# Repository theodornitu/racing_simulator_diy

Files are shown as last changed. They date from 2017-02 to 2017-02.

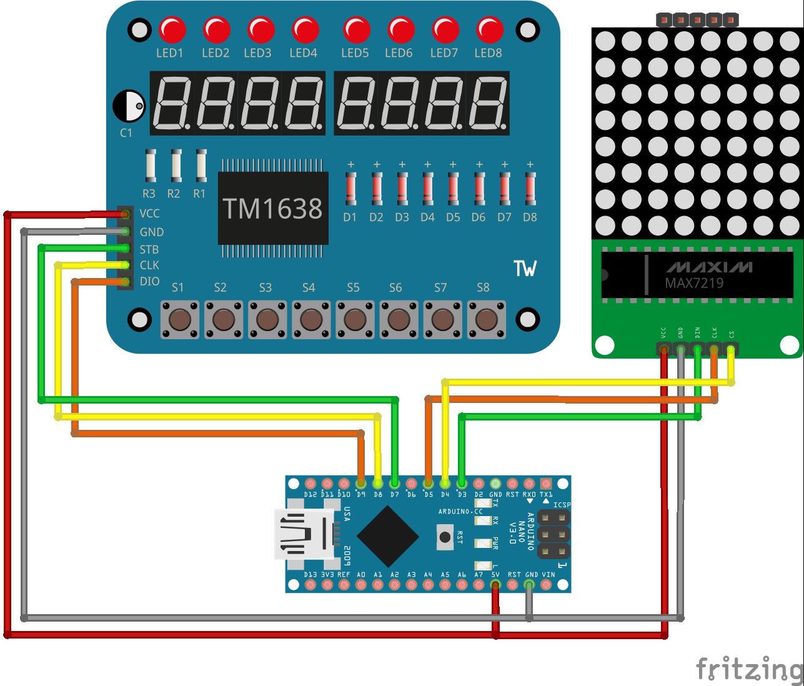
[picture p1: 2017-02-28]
Fritzing Sketch_bb.jpg

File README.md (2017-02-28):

# racing_simulator_diy
Some files that would help building a DIY racing simulator.

https://www.youtube.com/watch?v=rtt3L1Z49OM

Pentru pasionatii de simulatoare auto, pentru amatorii de gadget-uri tech, am pus cap la cap un
device pe care il puteti confectiona acasa, cu piese relativ ieftine si cu un rezultat foarte incurajator.

Toate piesele se pot cumpara de pe magazinul nostru, www.unda.tech/magazin . Folia de
carbon este optionala si nu este inclusa in KIT-ul disponibil online, aceasta se poate fabrica cu usurinta
urmand pasii din tutorial.

The software was provided by SimHub and is 100% their property.
For more information visit: https://github.com/zegreatclan/AssettoCorsaTools/wiki

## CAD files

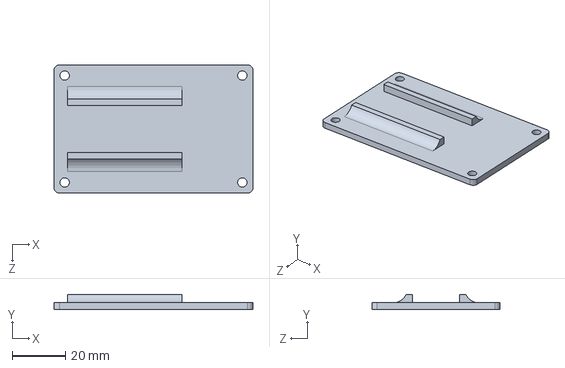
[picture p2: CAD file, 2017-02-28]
Parts/TM1368 backplate ard nano.SLDPRT
74.5 x 5.50 x 48.0 mm

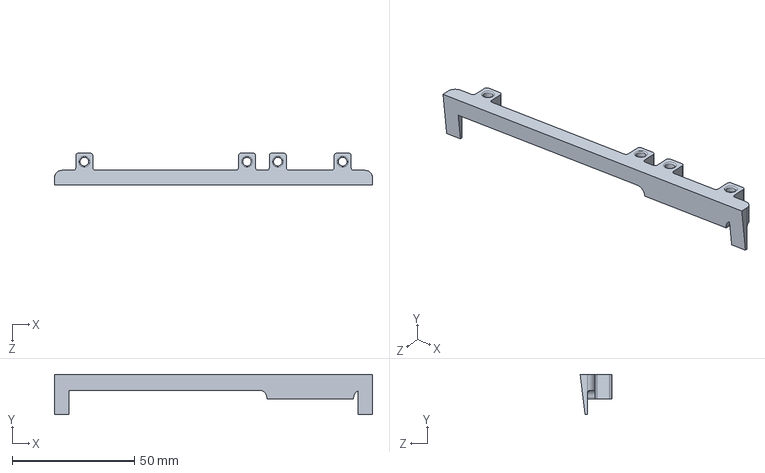
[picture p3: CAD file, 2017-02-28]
Parts/TM1368 Front_plate_and_feet.SLDPRT
130.0 x 16.4 x 13.0 mm

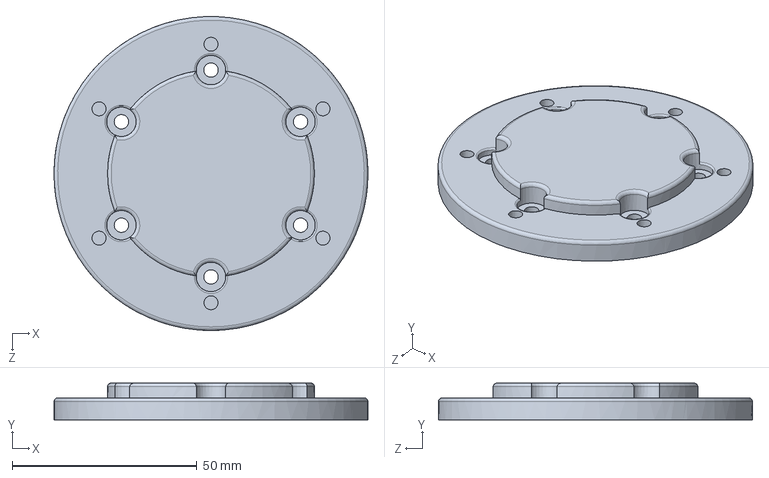
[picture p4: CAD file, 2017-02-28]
Parts/G29 Adapter.SLDPRT
85.0 x 10.0 x 85.0 mm

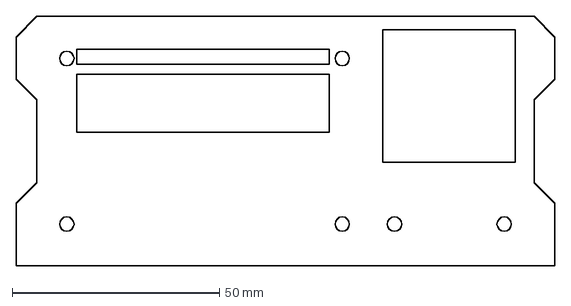
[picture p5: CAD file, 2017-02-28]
Parts/LCD_Dash_Carbon_Cut.DXF
130.0 x 60.1 mm

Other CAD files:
Parts/Part1.SLDPRT
Parts/G29 Adapter.STL
Parts/TM1368 Front_plate_and_feet.STL
Parts/TM1368 backplate ard nano.STL

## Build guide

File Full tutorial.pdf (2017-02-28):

## RACING DASH SIMULATOR

_____________________________________________________________________________________

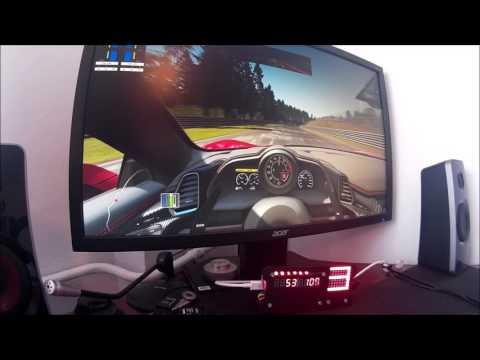
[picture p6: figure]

Pentru pasionatii de simulatoare auto, pentru amatorii de gadget-uri tech, am pus cap la cap un device pe care il puteti confectiona acasa, cu piese relativ ieftine si cu un rezultat foarte incurajator.

Lista componente si materiale necesare:

NUME | CANTITATE | MAGAZIN | PRET
TM1638 Keypad | 1 | UNDA Tech (https://magazin.unda.tech/ro/extensii/689-tm1638-keypad-module.html) | 44.9
Arduino Nano128P | 1 | UNDA Tech (https://magazin.unda.tech/ro/arduino/422-placa-de-dezvoltare-nano-168p.html?search_query=nano&results=4) | 19,9 RON
MAX7219 Dot Matrix | 1 | UNDA Tech (https://magazin.unda.tech/ro/tehnologie-led/212-max7219-diy.html?search_query=max&results=63) | 20 RON
Cabluri / fire diverse | 1 | UNDA Tech (https://magazin.unda.tech/ro/search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) | 10 RON
Panou plexiglass | 1 | UNDA Tech (https://magazin.unda.tech/ro/home/688-kit-panou-simulator-racing.html) | 34,9 RON
Set imprimat 3D
Folie carbon panou | OPTIONAL
TOTAL: 129,8 RON

Toate piesele se pot cumpara de pe magazinul nostru, www.unda.tech/magazin . Folia de carbon este optionala si nu este inclusa in KIT-ul disponibil online, aceasta se poate fabrica cu usurinta urmand pasii din tutorial.

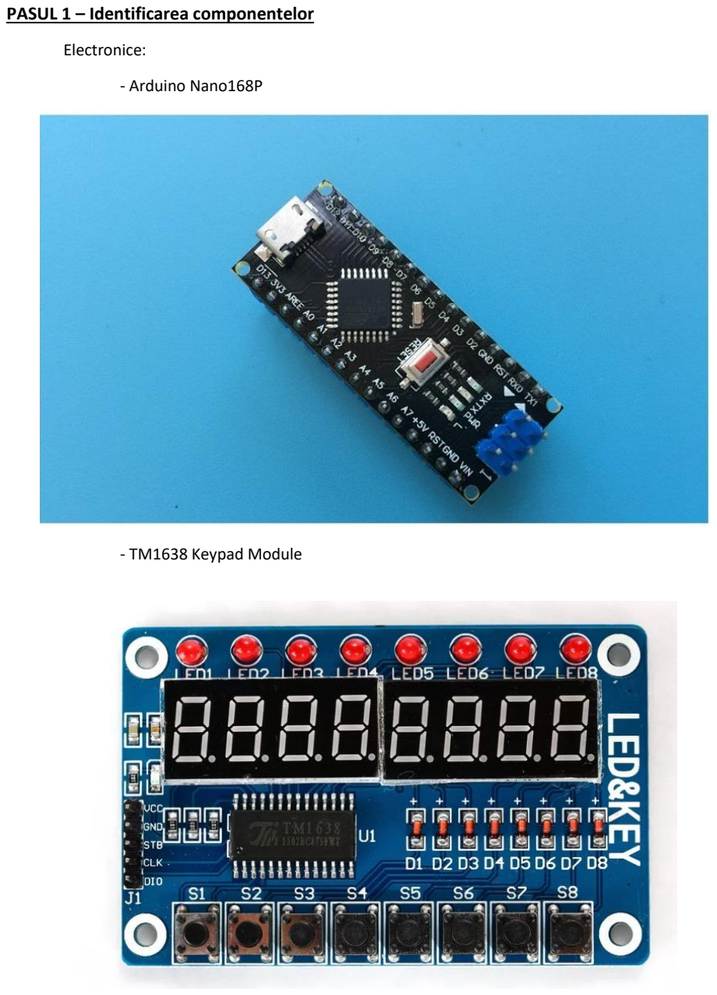
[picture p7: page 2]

PASUL 1 – Identificarea componentelor

Electronice:

- Arduino Nano168P
- TM1638 Keypad Module

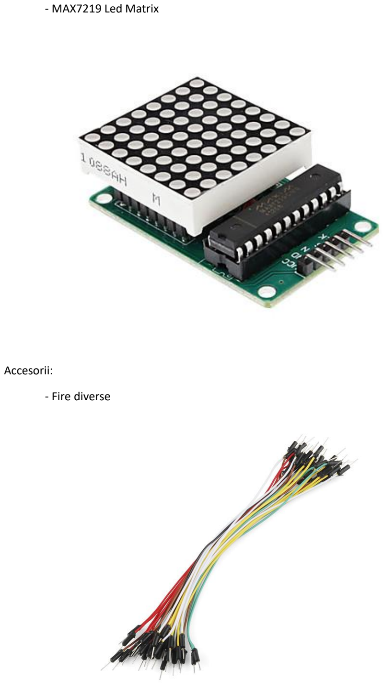
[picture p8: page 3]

- MAX7219 Led Matrix

Accesorii:

- Fire diverse

- Kit Panou plexiglass + piese imprimate 3D

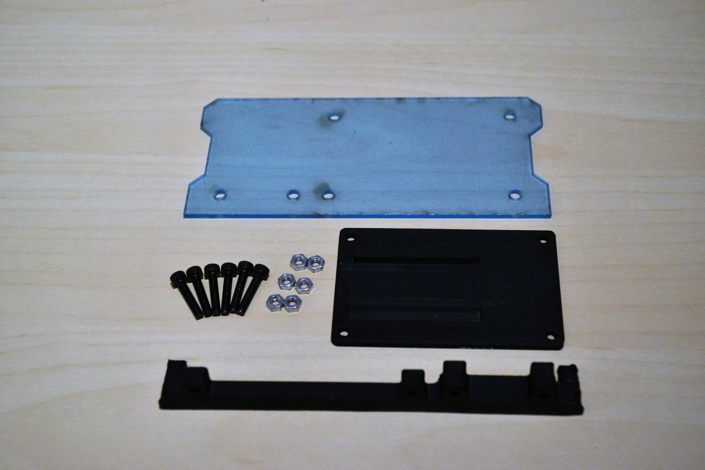
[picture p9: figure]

* kit-ul contine: - panou plexiglass transparent

- suport arduino nano ( backplate )
- stand Keypad si Led Matrix
- M3x25 (6buc) si M3 Nuts (6buc)

PASUL 2 – Conectarea componentelor electronice

Conectarea componentelor se va face dupa urmatoarea schema :

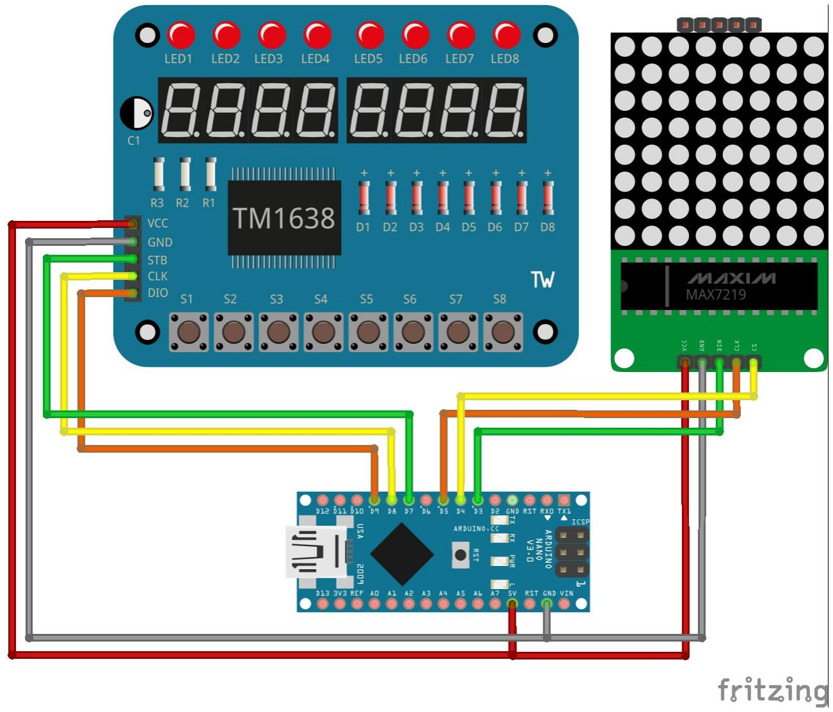
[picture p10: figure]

Part | Part Pin | Arduino Nano Pin
TM1638 KEYPAD MODULE | VCC | 5V
| GND | GND
| STB | D7
| CLK | D8
| DIO | D9
MAX7219 LED MATRIX MODULE | VCC | 5V
| GND | GND
| DIN | D3
| CLK | D5
| CS | D4

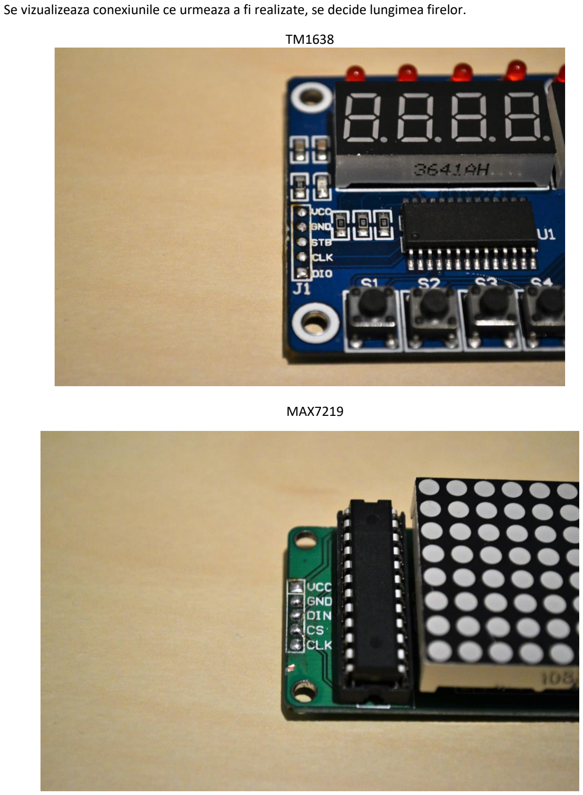
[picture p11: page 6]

Se vizualizeaza conexiunile ce urmeaza a fi realizate, se decide lungimea firelor.

TM1638

MAX7219

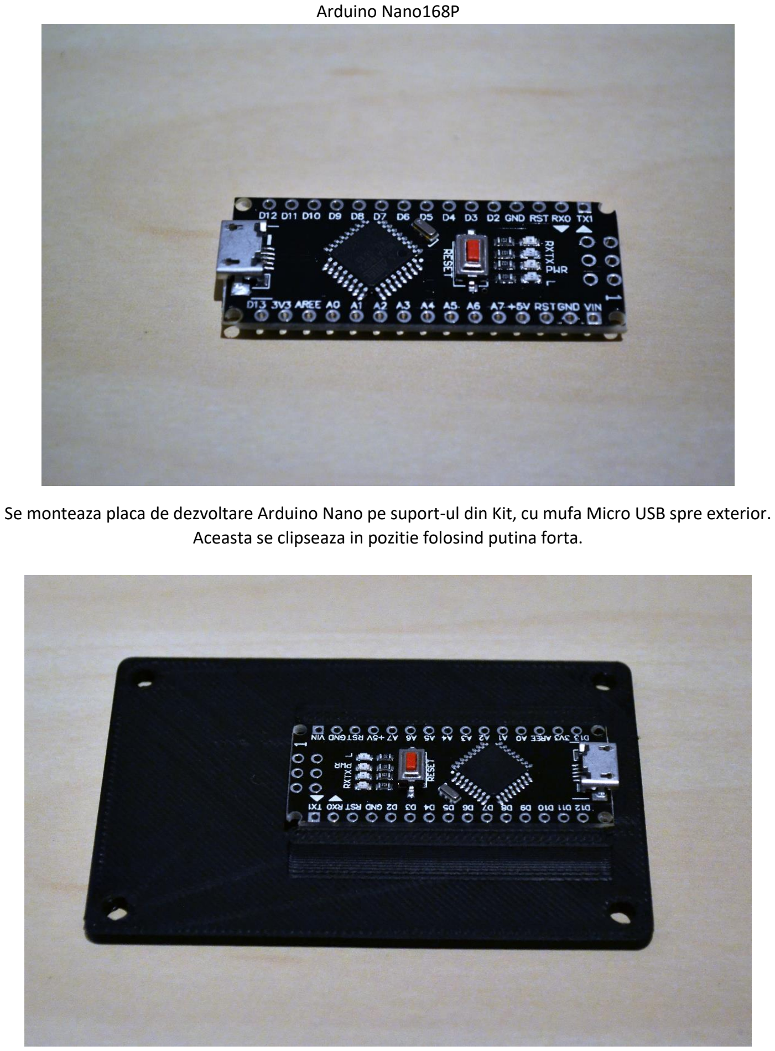
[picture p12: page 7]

Arduino Nano168P

Se monteaza placa de dezvoltare Arduino Nano pe suport-ul din Kit, cu mufa Micro USB spre exterior. Aceasta se clipseaza in pozitie folosind putina forta.

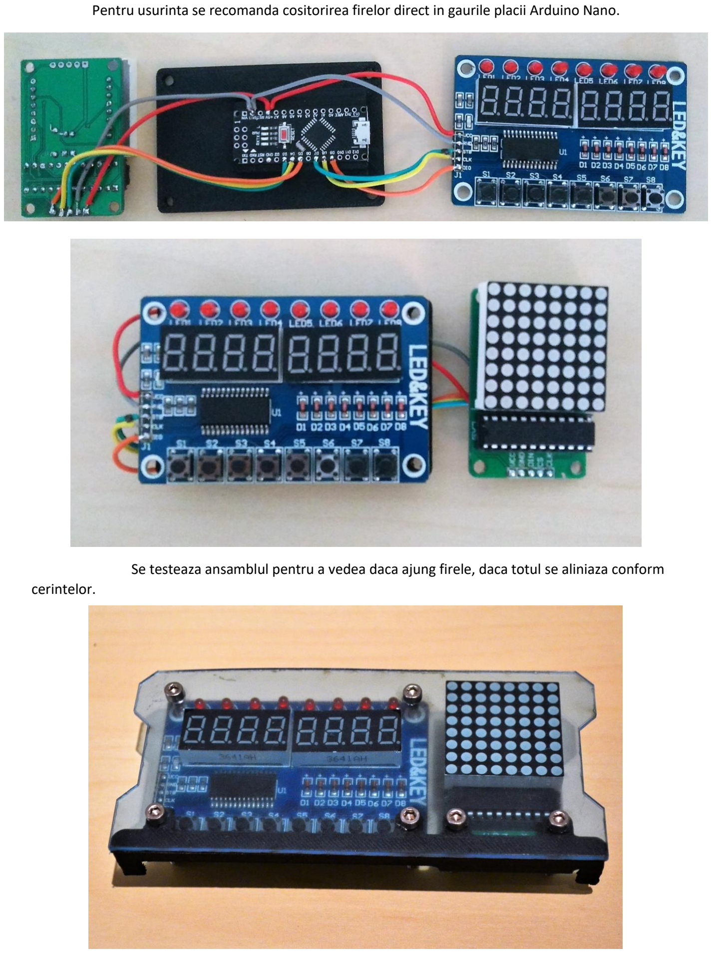
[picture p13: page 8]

Pentru usurinta se recomanda cositorirea firelor direct in gaurile placii Arduino Nano.

Se testeaza ansamblul pentru a vedea daca ajung firele, daca totul se aliniaza conform cerintelor.

PASUL 3 – Folie Carbon ( OPTIONAL )

- Se imprima desenul PDF atasat, folosind scara 1:1 .

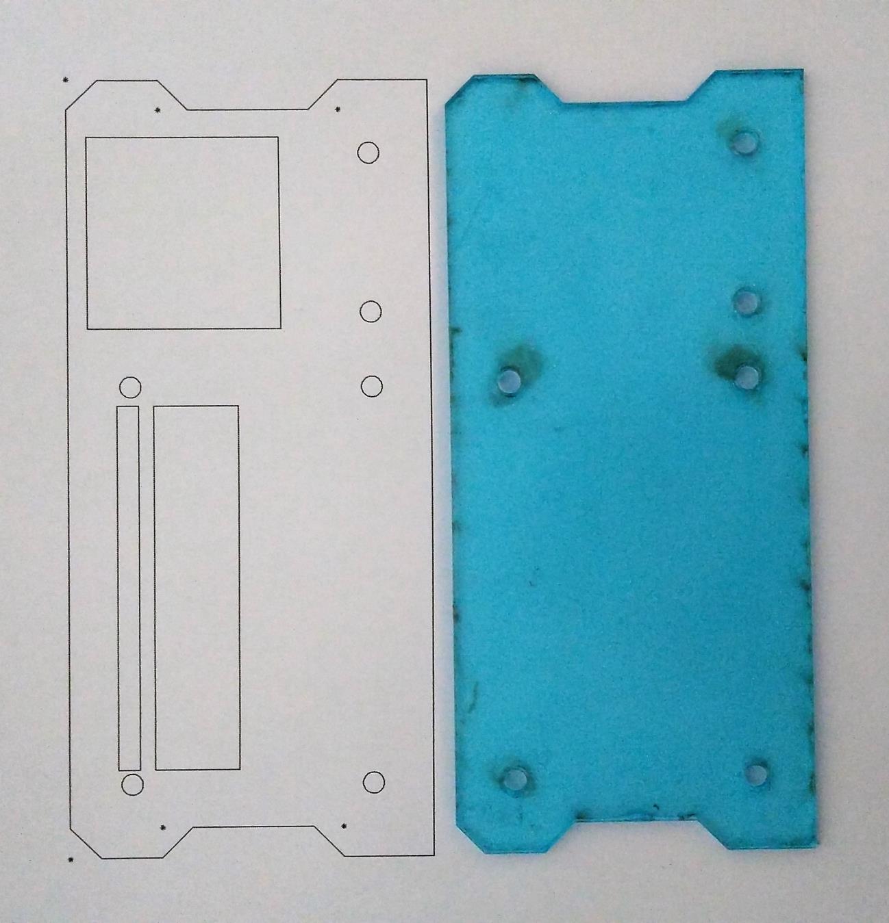
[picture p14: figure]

- folosind o rigla metalica si o lama de precizie ( sau un cutit foarte bine ascutit ) , se taie conturul imprimat si se decupeaza dreptunghiurile din interior. Daca aveti acces la un cutter plotter, desenele in format DXF vor fi disponibile in sectiunea resurse.

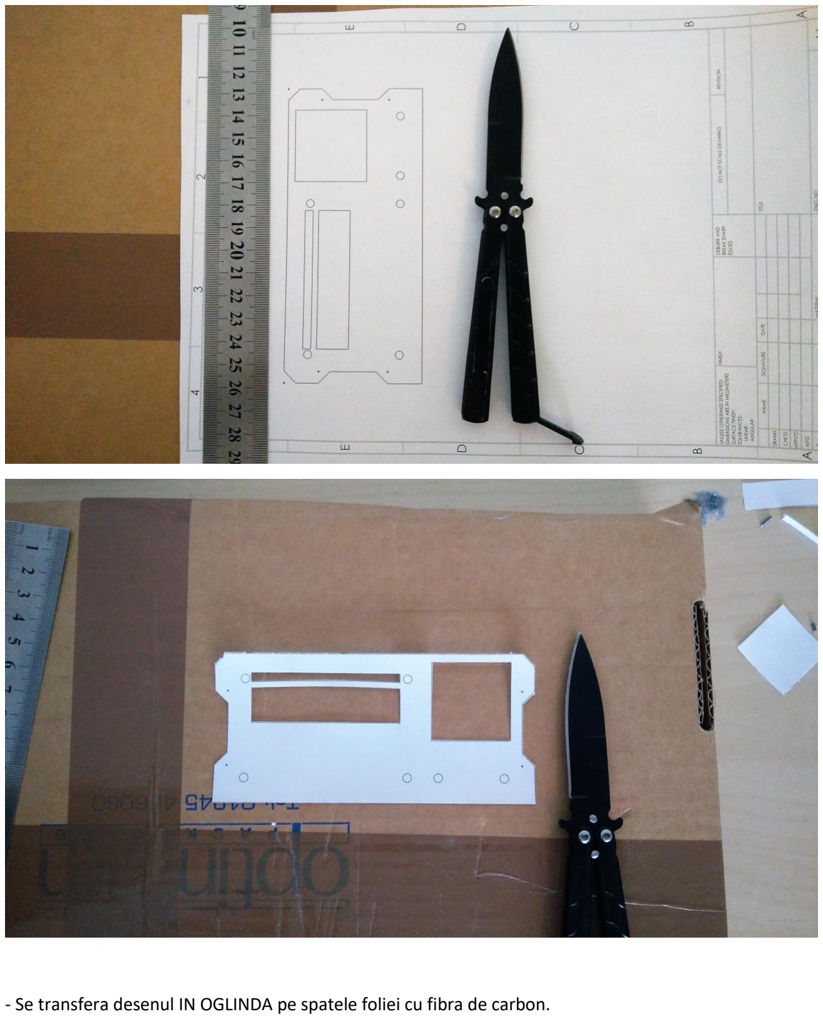
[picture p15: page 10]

- Se transfera desenul IN OGLINDA pe spatele foliei cu fibra de carbon.

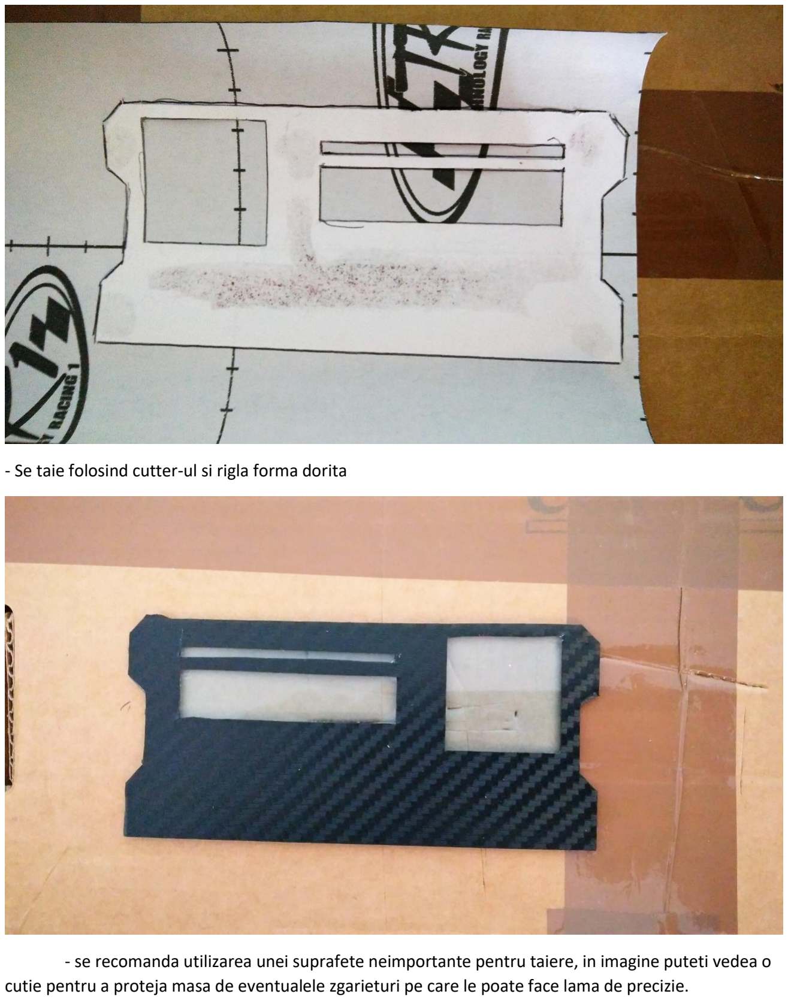
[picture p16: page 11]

- Se taie folosind cutter-ul si rigla forma dorita
- se recomanda utilizarea unei suprafete neimportante pentru taiere, in imagine puteti vedea o cutie pentru a proteja masa de eventualele zgarieturi pe care le poate face lama de precizie.

- se lipeste folia pe panoul de plexiglass si se curata eventualele imperfectiuni ramase in urma taierii:
- Se inteapa gaurile pentru suruburi si se introduc suruburile in gaurile lor. Se adauga stand-ul imprimat 3D peste acestea:

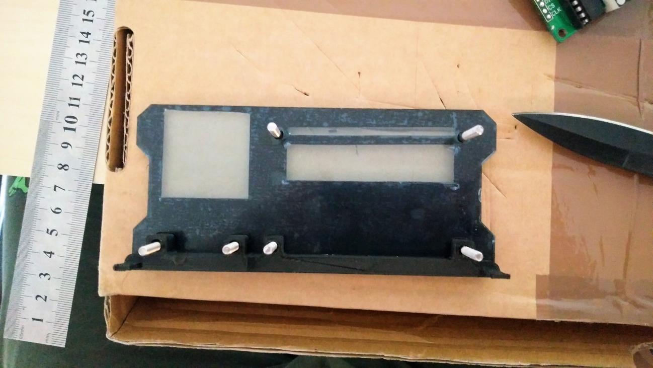
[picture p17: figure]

- Se monteaza modulul Keypad, Matrix si Arduino Nano pe panou utilizand suruburile si piulitele necesare (6 buc M3x25 si 6 buc piulite ). Se adauga folie carbon in zonele cu pini expusi pentru a preveni eventualele scurt-uri nedorite.

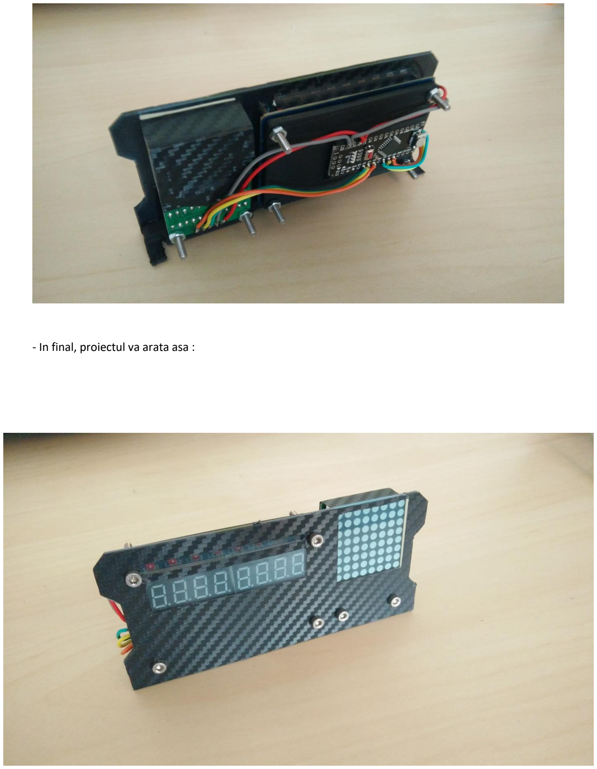
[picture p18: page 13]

- In final, proiectul va arata asa :

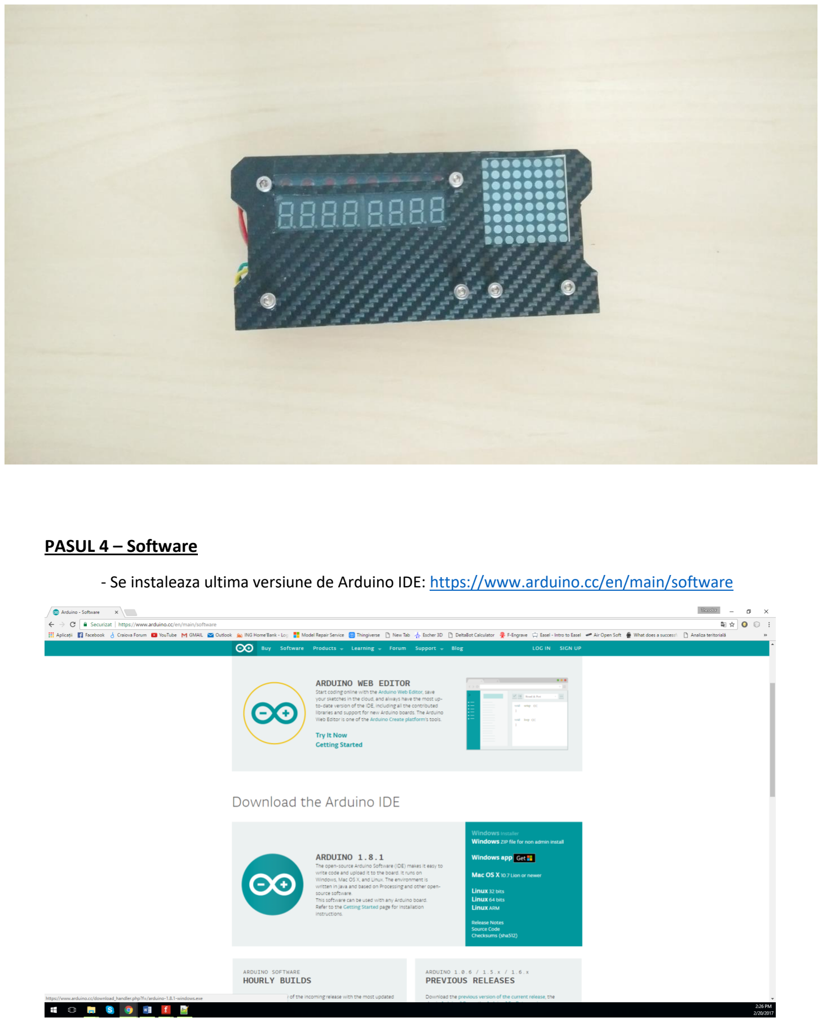
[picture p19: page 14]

PASUL 4 – Software

- Se instaleaza ultima versiune de Arduino IDE: https://www.arduino.cc/en/main/software

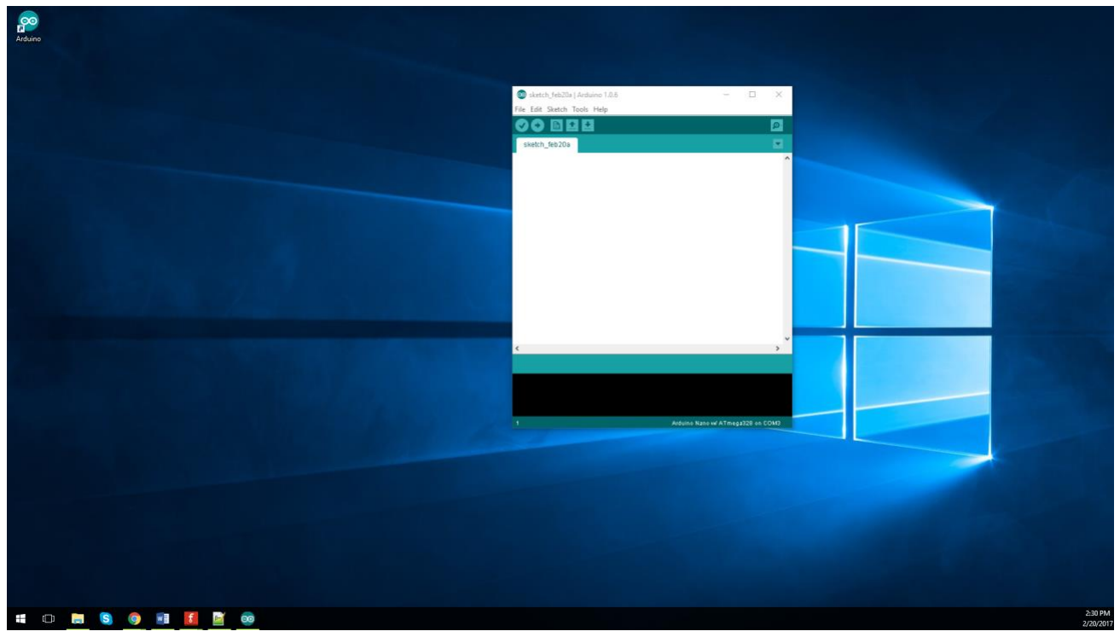
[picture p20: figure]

- Se instaleaza librariile necesare din locatia : Racing Simulator DIY Dash > Libraries . Acestea se copiaza in <<Arduino Install Folder>> > Libraries
- Se deschide codul sursa din locatia : Racing Simulator DIY Dash > Code > DisplayClientV2 > DisplayClientV2.ino
- Se selecteaza Arduino Nano168P (sau, in cazul folosirii unui arduino Nano328P, se selecteaza acesta) , port-ul la care se poate vedea placa de dezvoltare si se apasa butonul Upload

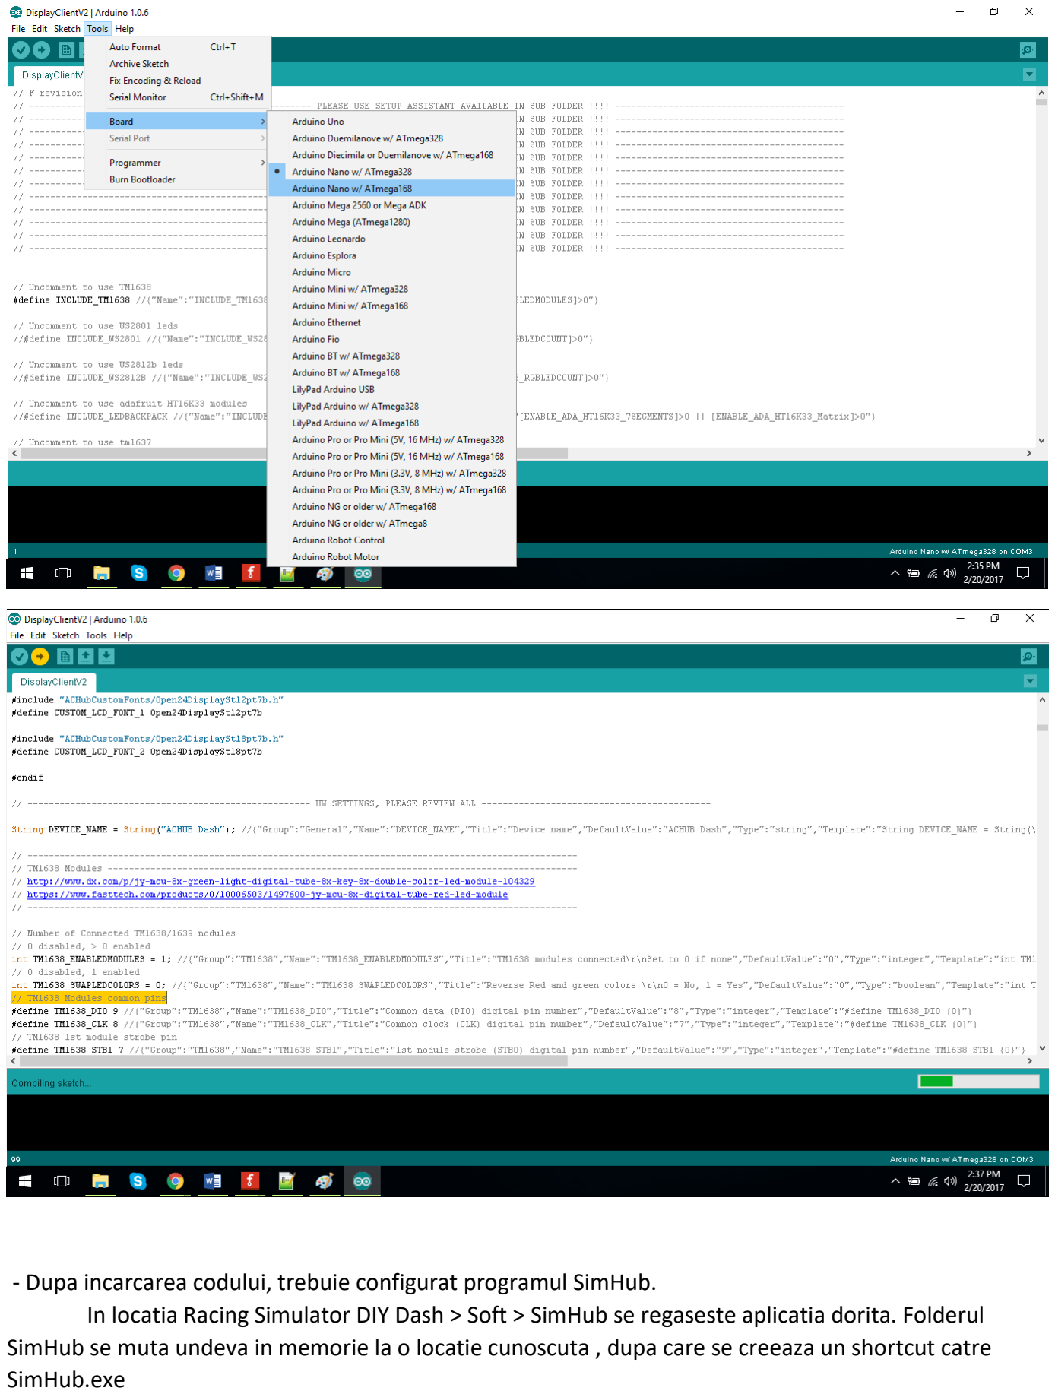
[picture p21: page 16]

- Dupa incarcarea codului, trebuie configurat programul SimHub.
In locatia Racing Simulator DIY Dash > Soft > SimHub se regaseste aplicatia dorita. Folderul SimHub se muta undeva in memorie la o locatie cunoscuta , dupa care se creeaza un shortcut catre SimHub.exe

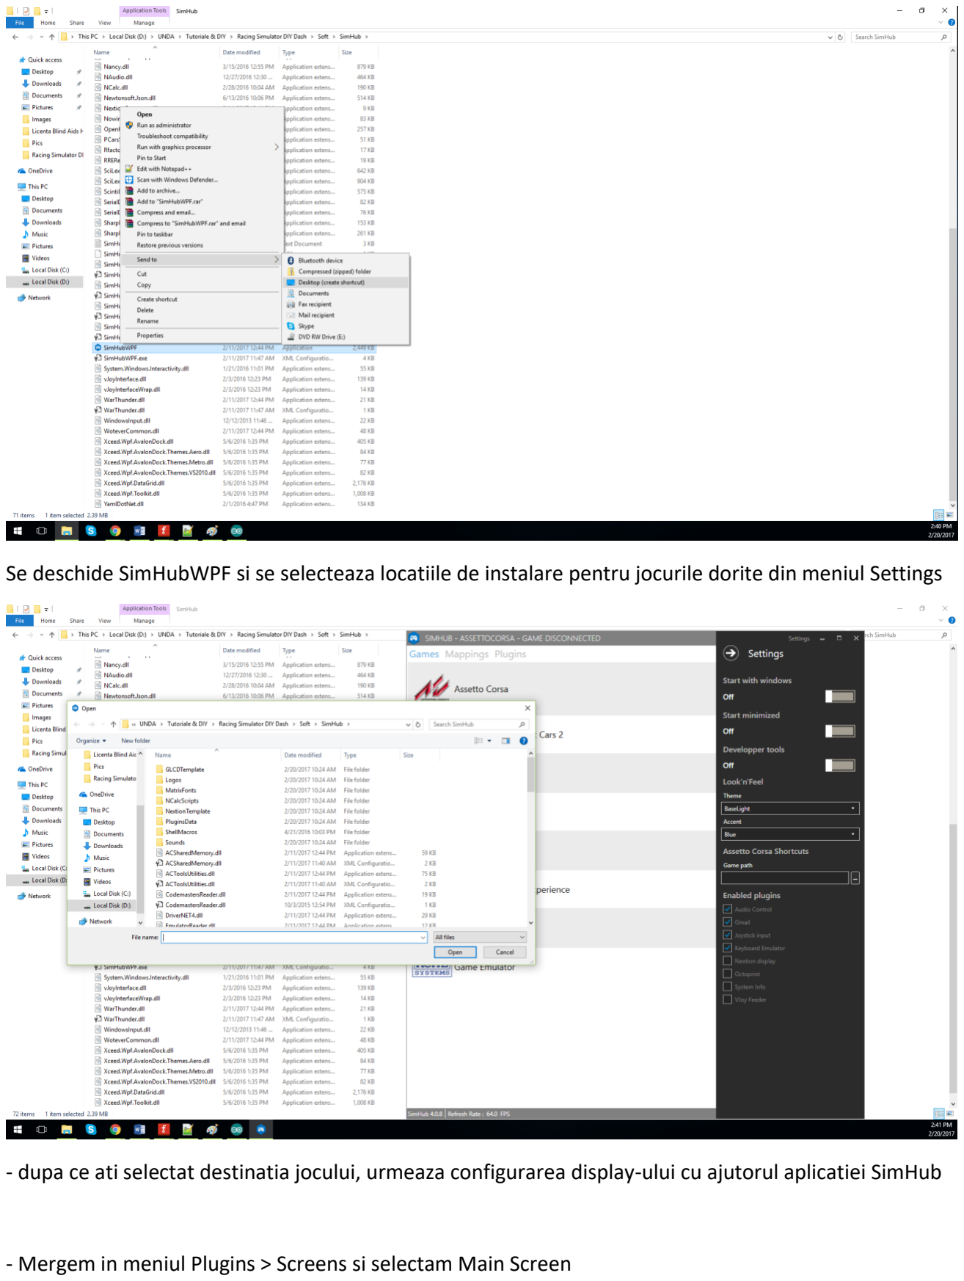
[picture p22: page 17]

Se deschide SimHubWPF si se selecteaza locatiile de instalare pentru jocurile dorite din meniul Settings

- dupa ce ati selectat destinatia jocului, urmeaza configurarea display-ului cu ajutorul aplicatiei SimHub
- Mergem in meniul Plugins > Screens si selectam Main Screen

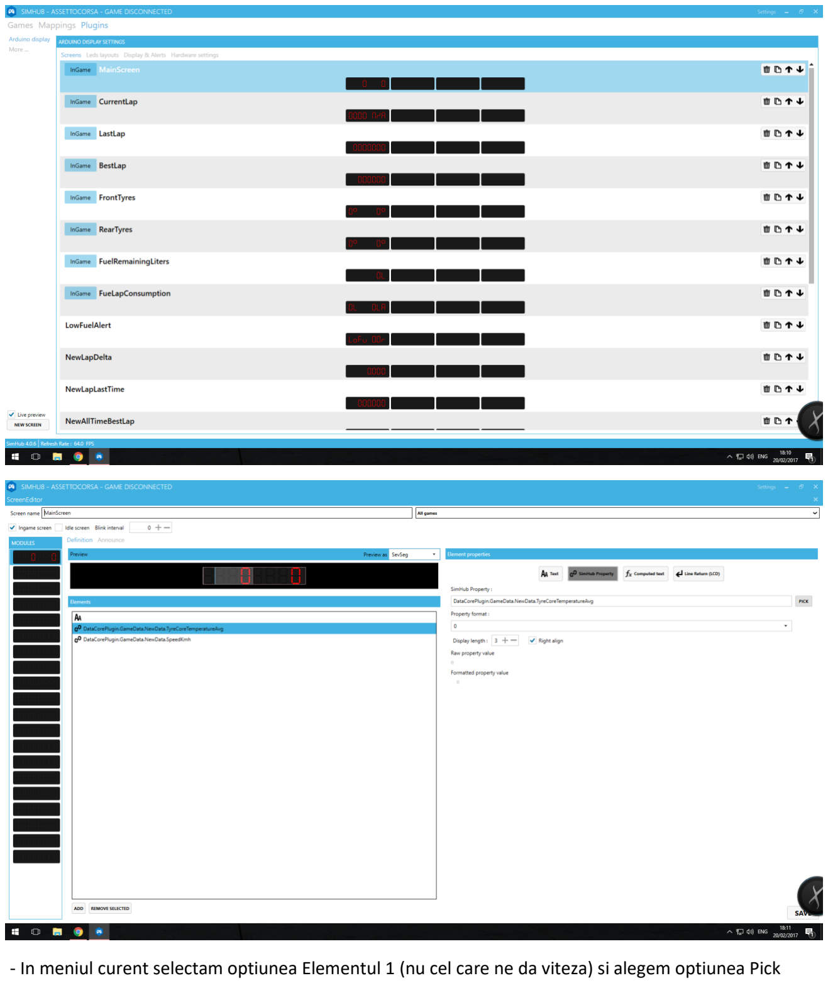
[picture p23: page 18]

- In meniul curent selectam optiunea Elementul 1 (nu cel care ne da viteza) si alegem optiunea Pick

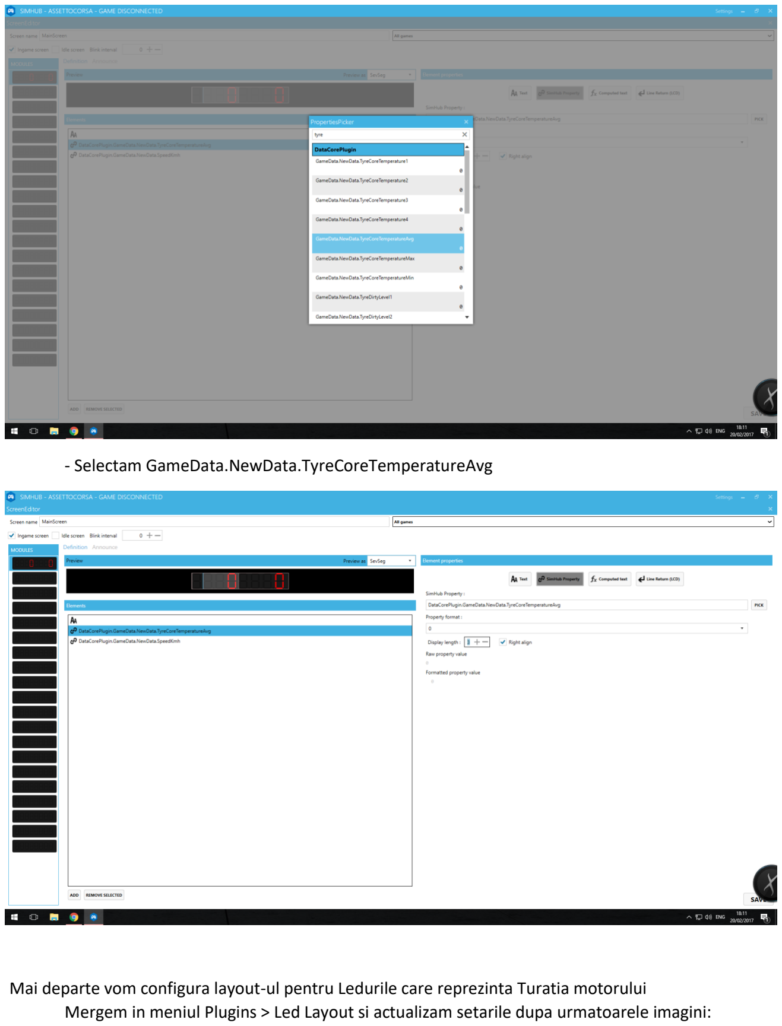
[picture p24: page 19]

- Selectam GameData.NewData.TyreCoreTemperatureAvg

Mai departe vom configura layout-ul pentru Ledurile care reprezinta Turatia motorului
Mergem in meniul Plugins > Led Layout si actualizam setarile dupa urmatoarele imagini:

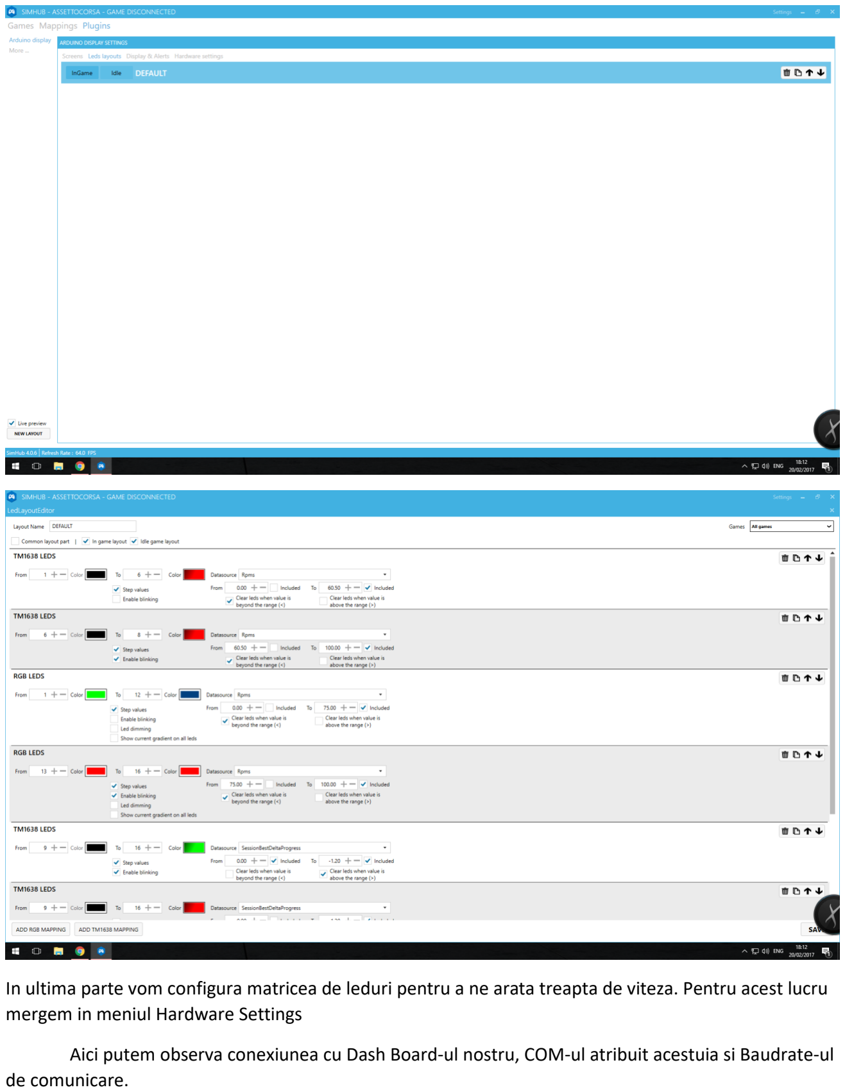
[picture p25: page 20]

In ultima parte vom configura matricea de leduri pentru a ne arata treapta de viteza. Pentru acest lucru mergem in meniul Hardware Settings

Aici putem observa conexiunea cu Dash Board-ul nostru, COM-ul atribuit acestuia si Baudrate-ul de comunicare.

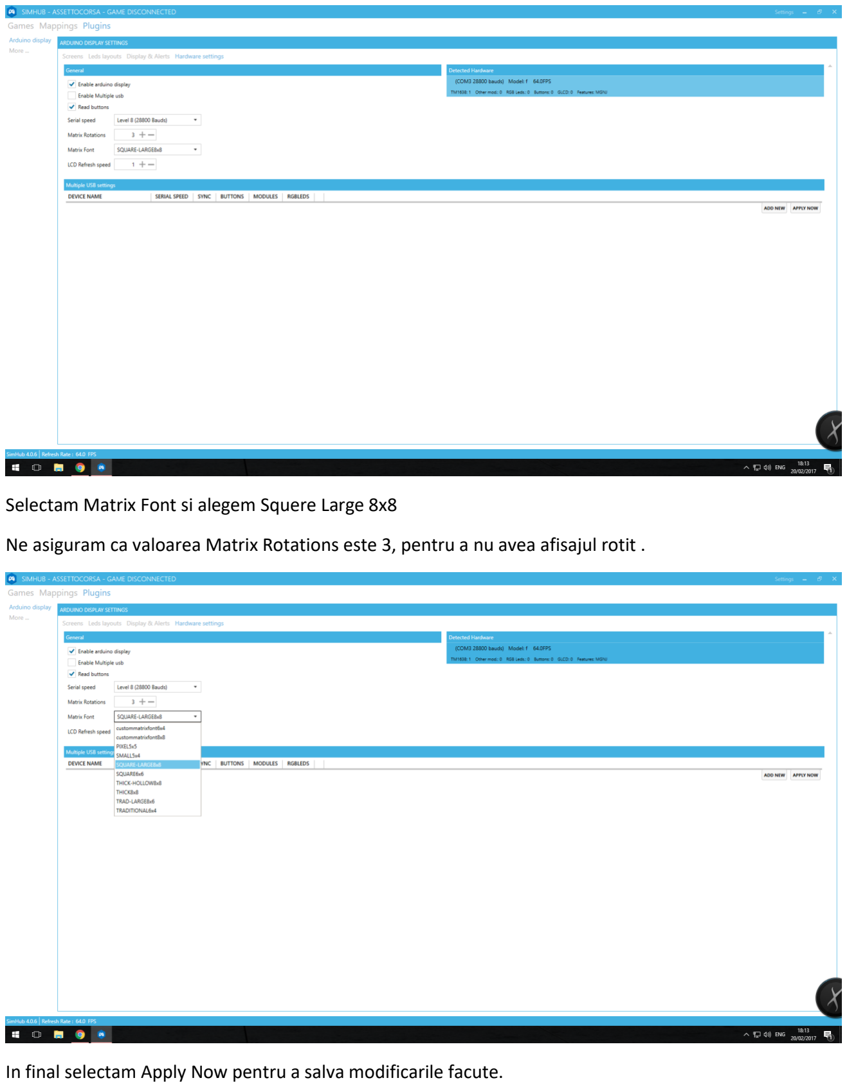
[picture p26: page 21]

Selectam Matrix Font si alegem Squere Large 8x8

Ne asiguram ca valoarea Matrix Rotations este 3, pentru a nu avea afisajul rotit .

In final selectam Apply Now pentru a salva modificarile facute.

Acum putem da Start Game din meniul SimHub pentru a initializa afisajul. ATENTIE! Afisajul va functiona numai daca jocul va fi pornit din meniul SimHub.

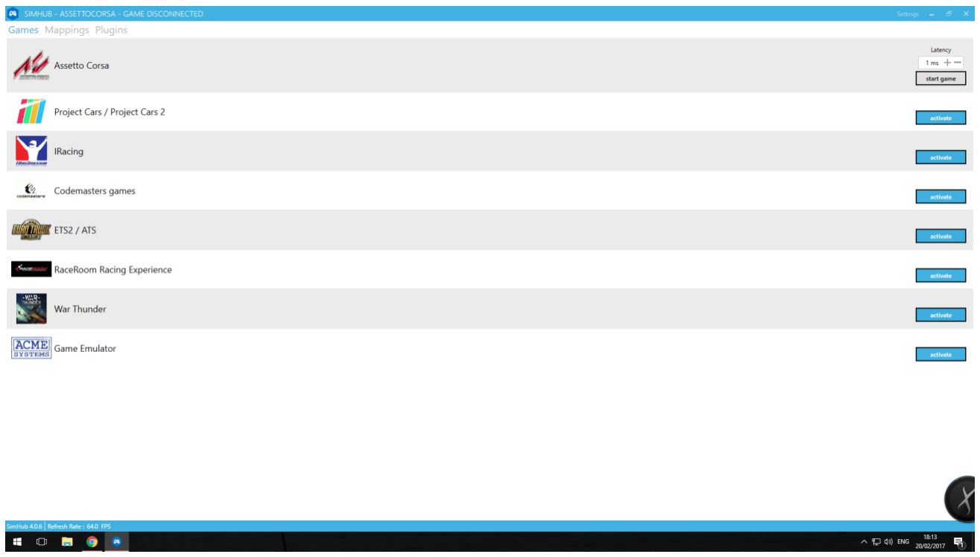
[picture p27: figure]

Acestea fiind spuse, ghidul nostru a ajuns la sfarsit! Pentru intrebari/sugestii nu ezitati sa ne contactati!

Material apartinand S.C UNDA Tech S.R.L . Distribuirea/modificarea/utilizarea este permisa. Acest material este gratuit si nu trebuie distribuit cu scop comercial.

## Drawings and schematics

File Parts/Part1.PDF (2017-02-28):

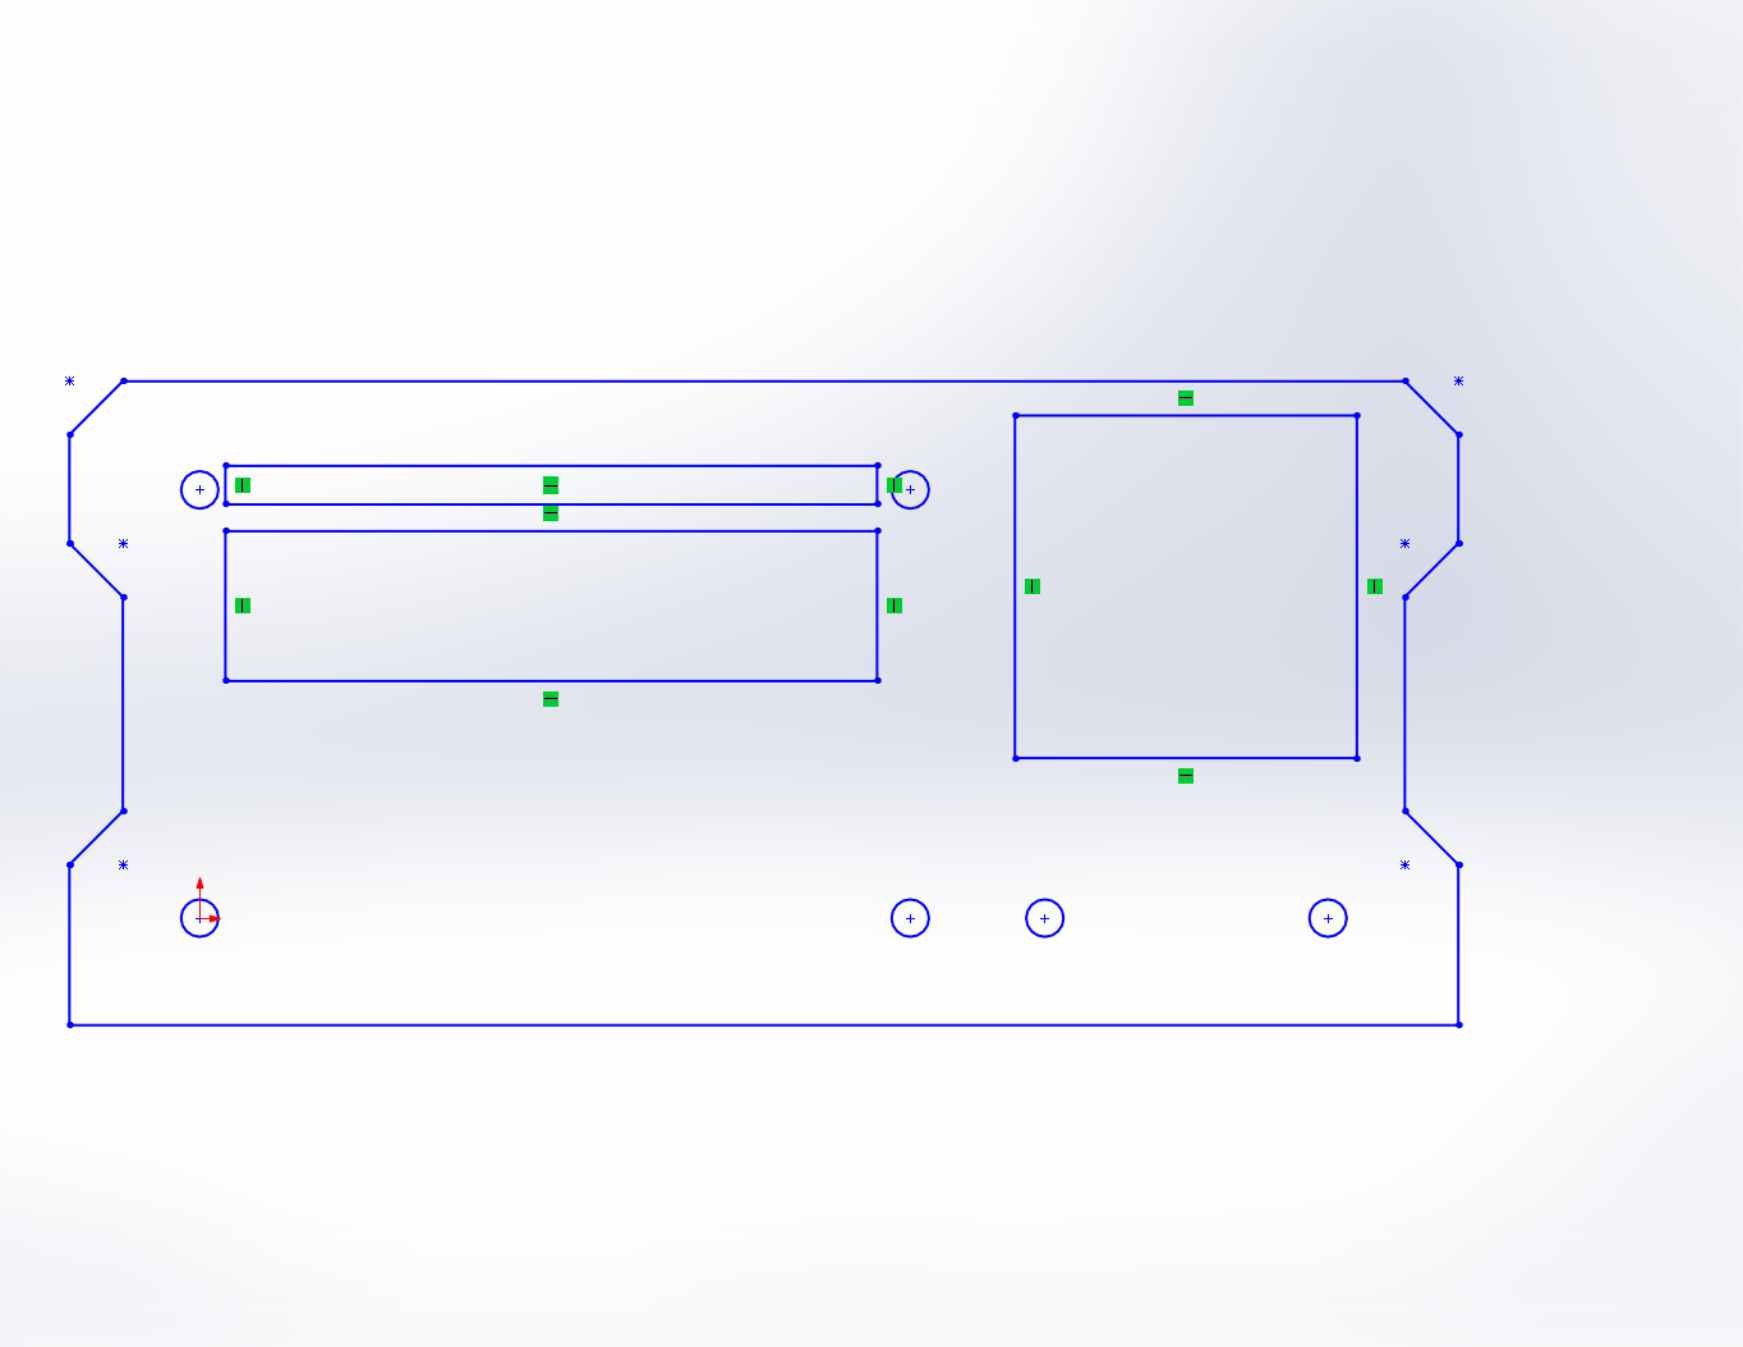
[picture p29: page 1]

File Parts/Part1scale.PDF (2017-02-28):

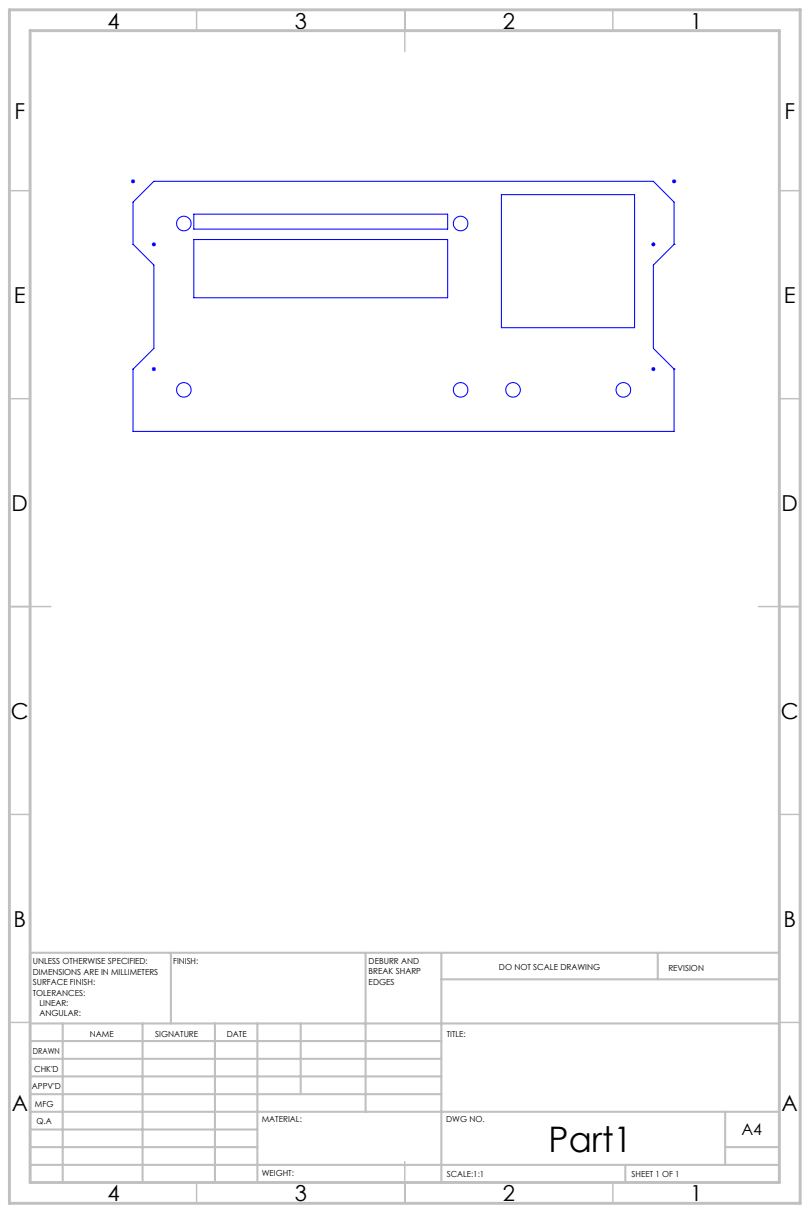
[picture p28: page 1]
FINISH:; DEBURR AND; BREAK SHARP; DO NOT SCALE DRAWING; REVISION; SCALE:1:1; SHEET 1 OF 1

UNLESS OTHERWISE SPECIFIED:
DIMENSIONS ARE IN MILLIMETERS
SURFACE FINISH:
TOLERANCES:
LINEAR:
ANGULAR:

NAME | SIGNATURE | DATE | | | | TITLE:

DRAWN
CHK'D
APPV'D
MFG
Q.A | | | | MATERIAL: | DWG NO. Part1 | A4
